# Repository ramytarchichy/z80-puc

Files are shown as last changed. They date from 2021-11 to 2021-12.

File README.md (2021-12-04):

# Z80 PUC

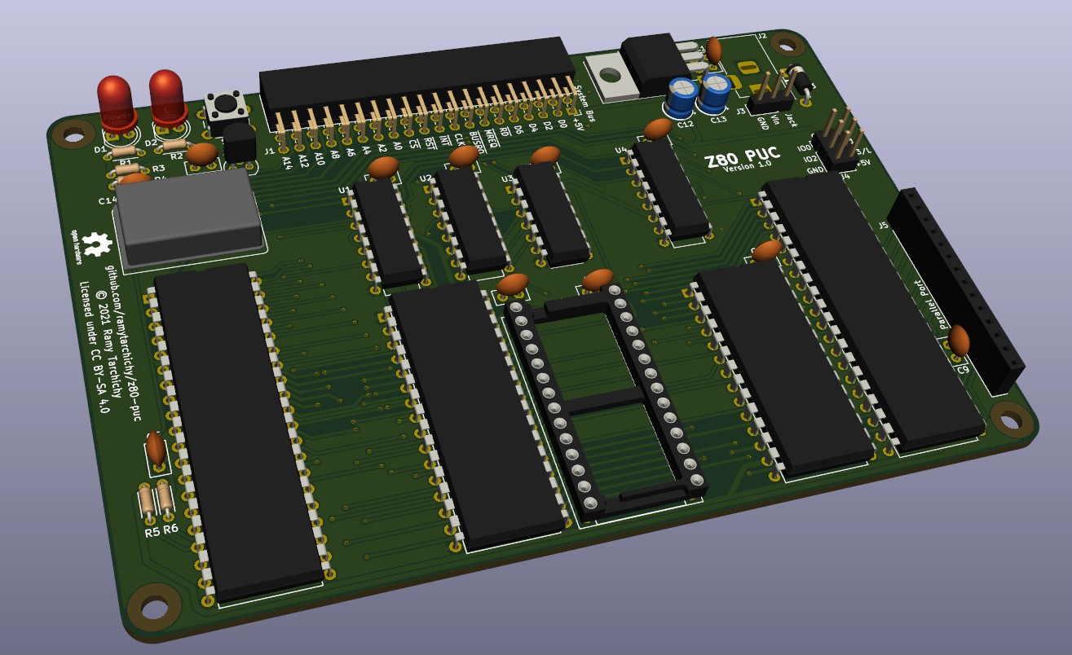
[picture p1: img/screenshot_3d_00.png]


Z80 PUC is a single-board Z80-based computer for embedded applications.

It's designed with all through-hole components for easy soldering and hacking,
as well as increased retro-cool factor. Despite its retro feel, all of its parts
are still readily available and in production as of writing this.

The goal is to have a Z80 "module" that can be quickly modified and then added
to a project instead of having to design and order a custom PCB every time.
Kind of like using a Raspberry Pi instead of designing your own ARM-based
computer for every project.

The "PUC" in Z80 **PUC** stands for "**P**revious **U**nit of **C**omputing".
Since the x86 CPUs in the Intel **NUC** (**N**ext **U**nit of **C**omputing) and
the Z80 both have a common ancestor (the Intel 8080 CPU), and both the NUC and
the Z80 PUC are small form factor computers, I thought it would be funny to call
them something similar.

# Memory map

## Memory

| From | To | Size | Use |
|---|---|---|---|
| `$0000` | `$1FFF` | 8K | ROM |
| `$2000` | `$3FFF` | 8K | Banked Area RAM |
| `$4000` | `$7FFF` | 16K  | Bus Expansion |
| `$8000` | `$FFFF` | 32K  | Static Area RAM |

## RAM Banks

The first 4 bits of Port B on the PIO select one out of 16 banks of 8K. The
static RAM area (`$8000`-`$FFFF`) is made up of 4 8K banks (`$C`-`$F`).

The total amount of addressable RAM built-in is 16x8K = 128K

## I/O

- The CTC uses I/O addresses `$00`-`$0F`.
- The PIO uses I/O addresses `$10`-`$1F`.

# Design choices

## Why a PIO instead of an SIO for interfacing with peripherals?

- The PIO gives us an additional 8 GPIO pins to play around with, 4 of which are
used for memory bank selection, and 1 for the on-board LED. Implementing those
without a PIO would increase component count, so since we're including it
regardless, might as well use it.
- Transferring 8 bits at a time is probably faster than serial, and if pin count
really is at a premium on your peripheral's microcontroller, you can still send
fewer bits at a time.
- The parallel interface works regardless of the peripheral's clock speed.
- It's what I already had lying around in the parts bin.

## Where are the CTC TRG and output pins?

I just included the CTC for timer interrupts. I've never needed any of the CTC's
other functionality, so I decided to save some space and not include a pin
header for that. If you really need it, you can just solder a few wires directly
to the board, or add an external CTC chip.

## Part Interchangeability

- 74HC137 <=> 74HC138
- AS6C1008 <=> AS6C4008
- AT28C64 <=> AT28C256

# License

Z80 PUC (c) by Ramy Tarchichy

Z80 PUC is licensed under a
Creative Commons Attribution-ShareAlike 4.0 International License.

You should have received a copy of the license along with this
work. If not, see [http://creativecommons.org/licenses/by-sa/4.0/](http://creativecommons.org/licenses/by-sa/4.0/).

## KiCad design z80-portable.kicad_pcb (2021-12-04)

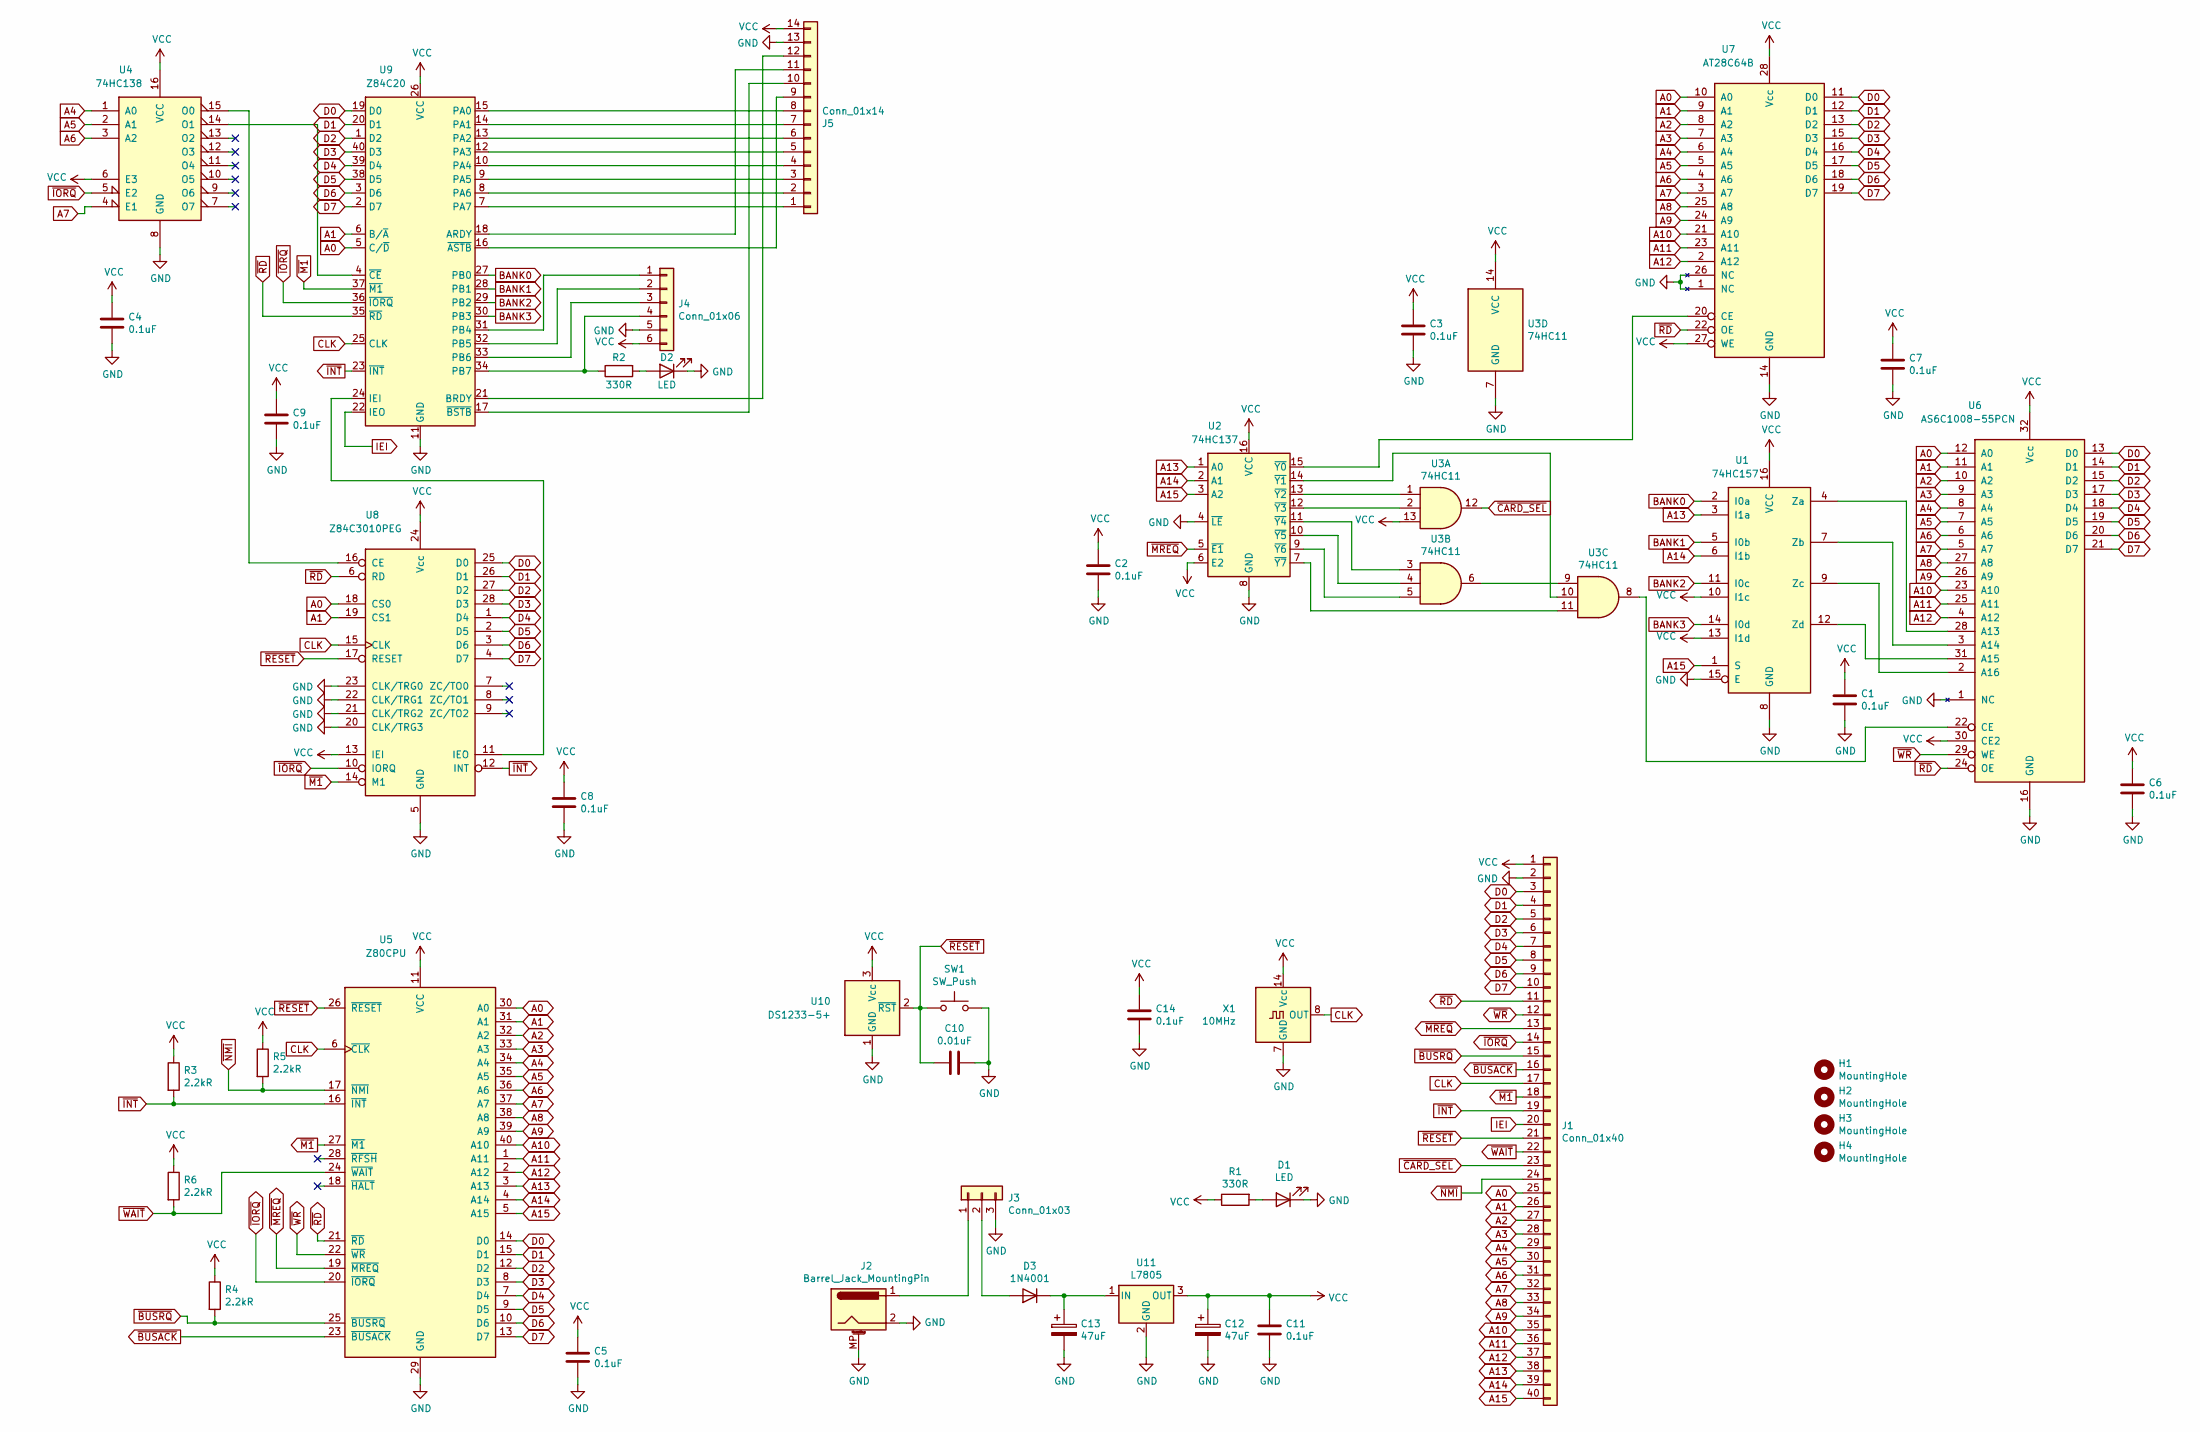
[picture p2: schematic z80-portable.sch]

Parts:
C1, C2, C3, C4, C5, C6, C7, C8, C9, C11, C14: 0.1uF; C_Disc_D5.0mm_W2.5mm_P2.50mm
C10: 0.01uF; C_Disc_D5.0mm_W2.5mm_P2.50mm
C12, C13: 47uF; CP_Radial_D5.0mm_P2.50mm
D1, D2: LED; LED_D5.0mm
D3: 1N4001; D_DO-41_SOD81_P7.62mm_Horizontal
H1, H2, H3, H4: MountingHole; MountingHole_3.2mm_M3
J1: Conn_01x40; PinSocket_2x20_P2.54mm_Horizontal
J2: Barrel_Jack_MountingPin; BarrelJack_Horizontal
J3: Conn_01x03; PinHeader_1x03_P2.54mm_Vertical
J4: Conn_01x06; PinHeader_2x03_P2.54mm_Vertical
J5: Conn_01x14; PinSocket_1x14_P2.54mm_Vertical
R1, R2: 330R; R_Axial_DIN0204_L3.6mm_D1.6mm_P5.08mm_Horizontal
R3, R4, R5, R6: 2.2kR; R_Axial_DIN0204_L3.6mm_D1.6mm_P5.08mm_Horizontal
SW1: SW_Push; SW_PUSH_6mm
U1: 74HC157; DIP-16_W7.62mm
U2: 74HC137; DIP-16_W7.62mm
U3: 74HC11; DIP-14_W7.62mm
U4: 74HC138; DIP-16_W7.62mm
U5: Z80CPU; DIP-40_W15.24mm
U6: AS6C1008-55PCN; DIP-32_W15.24mm
U7: AT28C64B; DIP-28_W15.24mm_Socket
U8: Z84C3010PEG; DIP-28_W15.24mm
U9: Z84C20; DIP-40_W15.24mm
U10: DS1233-5+; TO-92
U11: L7805; TO-220-3_Horizontal_TabDown
X1: 10MHz; Oscillator_DIP-14

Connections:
A0: J1.25, U5.30 (A0), U6.12 (A0), U7.10 (A0), U8.18 (CS0), U9.5 (C/~D~)
A1: J1.26, U5.31 (A1), U6.11 (A1), U7.9 (A1), U8.19 (CS1), U9.6 (B/~A~)
A2: J1.27, U5.32 (A2), U6.10 (A2), U7.8 (A2)
A3: J1.28, U5.33 (A3), U6.9 (A3), U7.7 (A3)
A4: J1.29, U4.1 (A0), U5.34 (A4), U6.8 (A4), U7.6 (A4)
A5: J1.30, U4.2 (A1), U5.35 (A5), U6.7 (A5), U7.5 (A5)
A6: J1.31, U4.3 (A2), U5.36 (A6), U6.6 (A6), U7.4 (A6)
A7: J1.32, U4.4 (E1), U5.37 (A7), U6.5 (A7), U7.3 (A7)
A8: J1.33, U5.38 (A8), U6.27 (A8), U7.25 (A8)
A9: J1.34, U5.39 (A9), U6.26 (A9), U7.24 (A9)
A10: J1.35, U5.40 (A10), U6.23 (A10), U7.21 (A10)
A11: J1.36, U5.1 (A11), U6.25 (A11), U7.23 (A11)
A12: J1.37, U5.2 (A12), U6.4 (A12), U7.2 (A12)
A13: J1.38, U1.3 (I1a), U2.1 (A0), U5.3 (A13)
A14: J1.39, U1.6 (I1b), U2.2 (A1), U5.4 (A14)
A15: J1.40, U1.1 (S), U2.3 (A2), U5.5 (A15)
BANK0: U1.2 (I0a), U9.27 (PB0)
BANK1: U1.5 (I0b), U9.28 (PB1)
BANK2: U1.11 (I0c), U9.29 (PB2)
BANK3: U1.14 (I0d), U9.30 (PB3)
CLK: J1.17, U5.6 (~CLK~), U8.15 (CLK), U9.25 (CLK), X1.8 (OUT)
D0: J1.3, U5.14 (D0), U6.13 (D0), U7.11 (D0), U8.25 (D0), U9.19 (D0)
D1: J1.4, U5.15 (D1), U6.14 (D1), U7.12 (D1), U8.26 (D1), U9.20 (D1)
D2: J1.5, U5.12 (D2), U6.15 (D2), U7.13 (D2), U8.27 (D2), U9.1 (D2)
D3: J1.6, U5.8 (D3), U6.17 (D3), U7.15 (D3), U8.28 (D3), U9.40 (D3)
D4: J1.7, U5.7 (D4), U6.18 (D4), U7.16 (D4), U8.1 (D4), U9.39 (D4)
D5: J1.8, U5.9 (D5), U6.19 (D5), U7.17 (D5), U8.2 (D5), U9.38 (D5)
D6: J1.9, U5.10 (D6), U6.20 (D6), U7.18 (D6), U8.3 (D6), U9.3 (D6)
D7: J1.10, U5.13 (D7), U6.21 (D7), U7.19 (D7), U8.4 (D7), U9.2 (D7)
GND: C1.2, C2.2, C3.2, C4.2, C5.2, C6.2, C7.2, C8.2, C9.2, C10.1, C11.2, C12.2, C13.2, C14.2, D1.1 (K), D2.1 (K), J1.2, J2.2, J2.MP (MountPin), J3.3, J4.5, J5.13, SW1.2, U1.8 (GND), U1.15 (E), U2.4 (~LE), U2.8 (GND), U3.7 (GND), U4.8 (GND), U5.29 (GND), U6.1 (NC), U6.16 (GND), U7.1 (NC), U7.14 (GND), U7.26 (NC), U8.5 (GND), U8.20 (CLK/TRG3), U8.21 (CLK/TRG2), U8.22 (CLK/TRG1), U8.23 (CLK/TRG0), U9.11 (GND), U10.1 (GND), U11.2 (GND), X1.7 (GND)
IEI: J1.20, U9.22 (IEO)
unnamed: C13.1, D3.1 (K), U11.1 (IN)
unnamed: D1.2 (A), R1.2
unnamed: D2.2 (A), R2.2
unnamed: D3.2 (A), J3.2
unnamed: J2.1, J3.1
unnamed: J4.1, U9.31 (PB4)
unnamed: J4.2, U9.32 (PB5)
unnamed: J4.3, U9.33 (PB6)
unnamed: J4.4, R2.1, U9.34 (PB7)
unnamed: J5.1, U9.7 (PA7)
unnamed: J5.2, U9.8 (PA6)
unnamed: J5.3, U9.9 (PA5)
unnamed: J5.4, U9.10 (PA4)
unnamed: J5.5, U9.12 (PA3)
unnamed: J5.6, U9.13 (PA2)
unnamed: J5.7, U9.14 (PA1)
unnamed: J5.8, U9.15 (PA0)
unnamed: J5.9, U9.16 (~ASTB~)
unnamed: J5.10, U9.17 (~BSTB~)
unnamed: J5.11, U9.18 (ARDY)
unnamed: J5.12, U9.21 (BRDY)
unnamed: U1.4 (Za), U6.28 (A13)
unnamed: U1.7 (Zb), U6.3 (A14)
unnamed: U1.9 (Zc), U6.2 (A16)
unnamed: U1.12 (Zd), U6.31 (A15)
unnamed: U2.7 (~Y7), U3.11
unnamed: U2.9 (~Y6), U3.5
unnamed: U2.10 (~Y5), U3.4
unnamed: U2.11 (~Y4), U3.3
unnamed: U2.12 (~Y3), U3.2
unnamed: U2.13 (~Y2), U3.1
unnamed: U2.14 (~Y1), U3.10
unnamed: U2.15 (~Y0), U7.20 (CE)
unnamed: U3.6, U3.9
unnamed: U3.8, U6.22 (CE)
unnamed: U4.14 (O1), U9.4 (~CE~)
unnamed: U4.15 (O0), U8.16 (CE)
unnamed: U8.11 (IEO), U9.24 (IEI)
VCC: C1.1, C2.1, C3.1, C4.1, C5.1, C6.1, C7.1, C8.1, C9.1, C11.1, C12.1, C14.1, J1.1, J4.6, J5.14, R1.1, R3.1, R4.1, R5.1, R6.1, U1.10 (I1c), U1.13 (I1d), U1.16 (VCC), U2.6 (E2), U2.16 (VCC), U3.13, U3.14 (VCC), U4.6 (E3), U4.16 (VCC), U5.11 (VCC), U6.30 (CE2), U6.32 (Vcc), U7.27 (WE), U7.28 (Vcc), U8.13 (IEI), U8.24 (Vcc), U9.26 (VCC), U10.3 (Vcc), U11.3 (OUT), X1.14 (Vcc)
~BUSACK: J1.16, U5.23 (~BUSACK~)
~BUSRQ: J1.15, R4.2, U5.25 (~BUSRQ~)
~CARD_SEL: J1.23, U3.12
~INT: J1.19, R3.2, U5.16 (~INT~), U8.12 (INT), U9.23 (~INT~)
~IORQ: J1.14, U4.5 (E2), U5.20 (~IORQ~), U8.10 (IORQ), U9.36 (~IORQ~)
~M1: J1.18, U5.27 (~M1~), U8.14 (M1), U9.37 (~M1~)
~MREQ: J1.13, U2.5 (~E1), U5.19 (~MREQ~)
~NMI: J1.24, R5.2, U5.17 (~NMI~)
~RD: J1.11, U5.21 (~RD~), U6.24 (OE), U7.22 (OE), U8.6 (RD), U9.35 (~RD~)
~RESET: C10.2, J1.21, SW1.1, U5.26 (~RESET~), U8.17 (RESET), U10.2 (~RST)
~WAIT: J1.22, R6.2, U5.24 (~WAIT~)
~WR: J1.12, U5.22 (~WR~), U6.29 (WE)

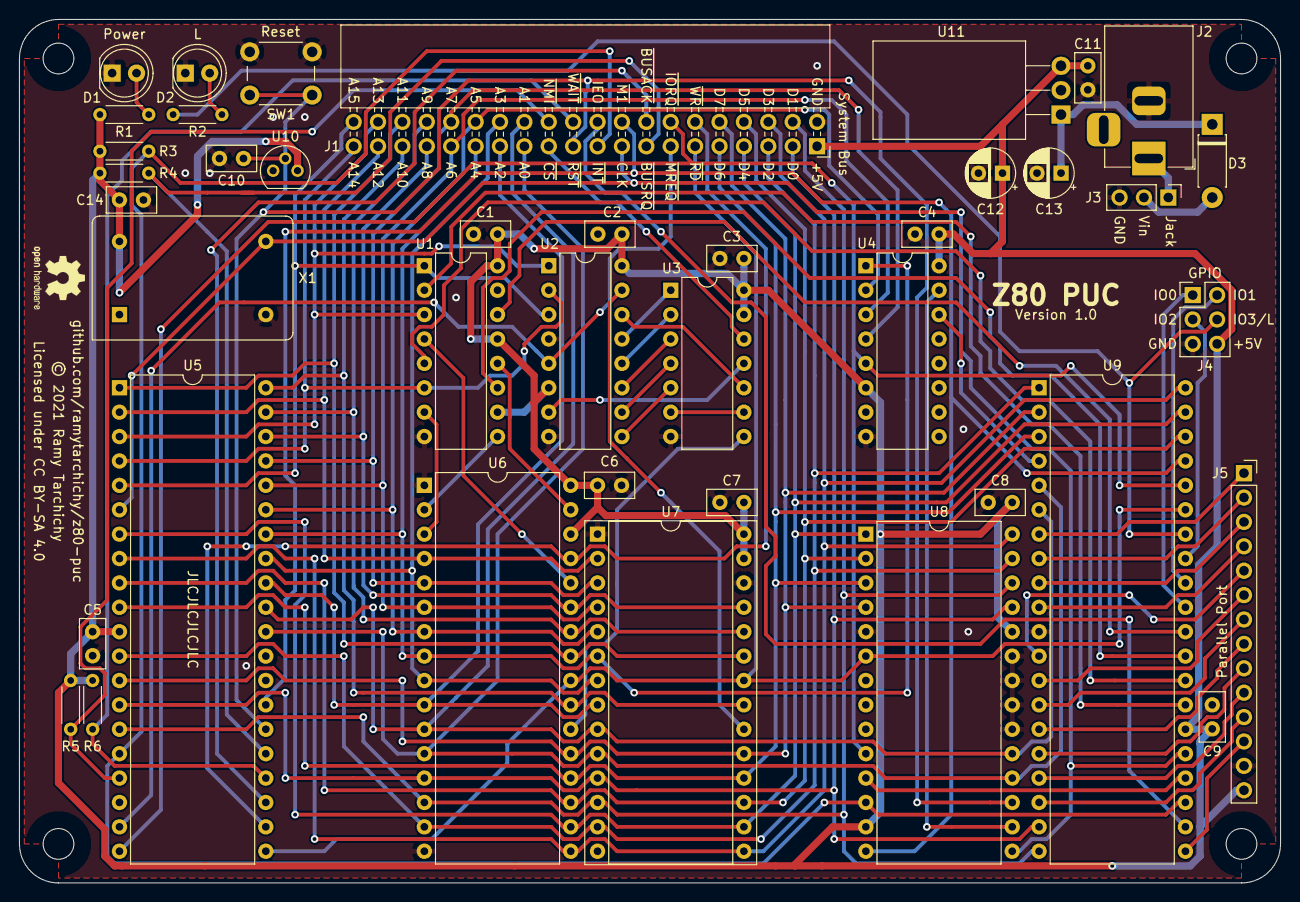
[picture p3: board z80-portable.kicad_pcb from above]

Board: 2 copper layers, 131.3 x 89.9 mm, 45 parts (0 on the bottom side), 82 nets.

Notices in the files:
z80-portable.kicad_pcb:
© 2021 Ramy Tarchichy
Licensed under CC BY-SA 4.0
